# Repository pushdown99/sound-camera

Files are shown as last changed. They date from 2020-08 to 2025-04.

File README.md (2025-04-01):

---
title: (2020) 서울 하드웨어 해커톤 - 탑메이커' 
author: haeyeon.hwang
tags: [tizen, rpi, iot]
---

# (2020)서울하드웨어해커톤 - 탑메이커
---
1. [팀명 및 팀원](#팀명-및-팀원)
2. [프로젝트 제목](#프로젝트-제목) 
3. [프로젝트 배경 및 목적](#프로젝트-배경-및-목적)
4. [타이젠 오픈소스에 컨트리뷰션한 내역](#타이젠-오픈소스에-컨트리뷰션한-내역)
5. [파일리스트](#파일리스트)
6. [코드 기여자](#코드-기여자)
7. [보드](#보드)
8. [구현 사항 가산점](#구현-사항-가산점)

---

[별첨](#별첨)

Watch the video (https://www.youtube.com/watch?v=p-jtZBpTV6w)
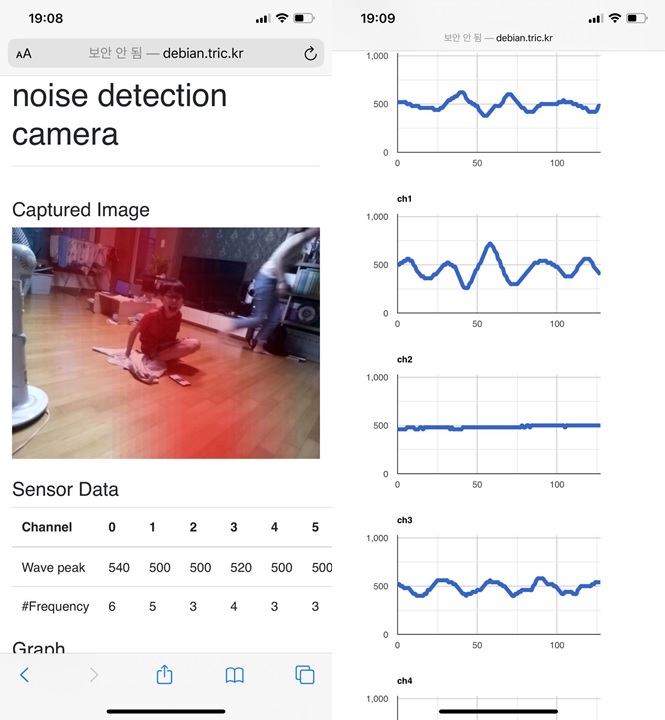
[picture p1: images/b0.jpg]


---

## 팀명 및 팀원
- 팀명: WNB
- 팀원 
   
이름|역할
---|---
황해연|기획/설계/개발(하드웨어/소프트웨어)
김민전|개발(소프트웨어)
황인규|기획/테스트
황인후|테스트

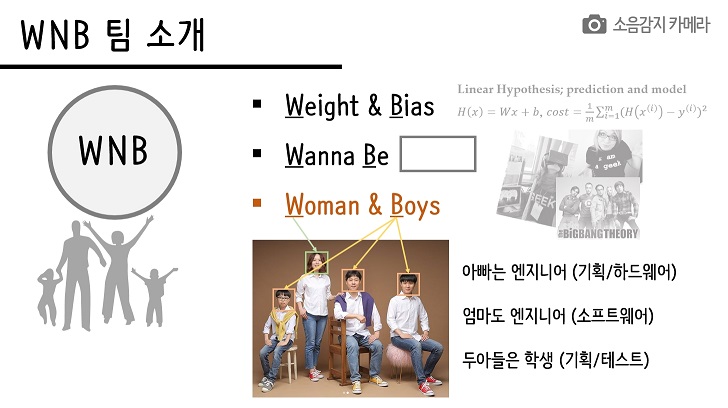
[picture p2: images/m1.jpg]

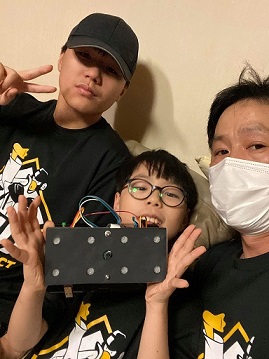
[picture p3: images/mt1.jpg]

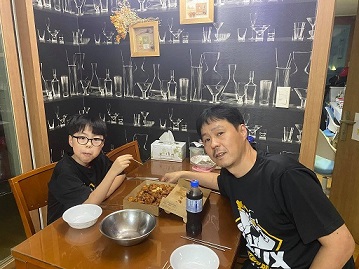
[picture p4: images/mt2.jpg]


---

## 프로젝트 제목

**소음감지 카메라 (Noise detection camera)**

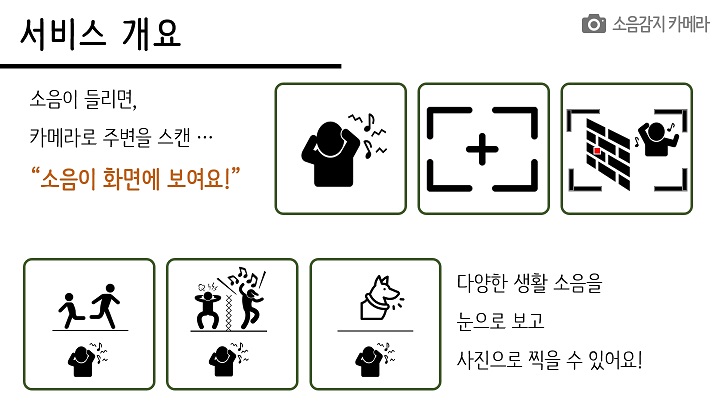
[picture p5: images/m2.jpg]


---

## 프로젝트 배경 및 목적 
#### 배경
- 코로나확산 따른 재택근무, 개학연기, 외출자제 추세
- 집콕족 증가에 따른이웃 간 층간소음 갈등 급증
- 소음원인별 층간소음 분류, 원인미상의 층간소음이 13%
- 층간소음의 사후증명은 어렵고, 분쟁의 불씨가 여전함

#### 하고자 하는것
- 층간소음이나 기타 원인음을 카메라처럼 찍을 수 있다면?
- **소음감지카메라**

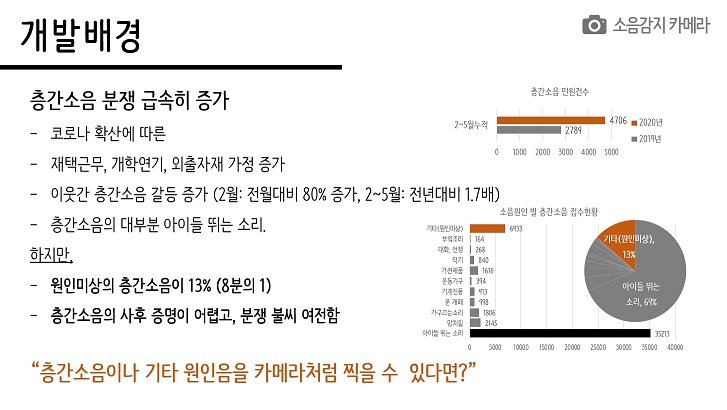
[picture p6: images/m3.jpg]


---

## 타이젠 오픈소스에 컨트리뷰션한 내역
내역없음

---

## 파일리스트
  
#### 소음감지카메라 [[github]](https://github.com/pushdown99/sound-camera/tree/master/camera)
~~~console
├─camera
│  ├─inc
│  ├─shared
│  │  └─res
│  └─src
~~~

- 헤더파일(*.h)

파일명|내용
---|---
inc/baseUI.h|baseUI/EFL 관련 외부참조 및 함수정의 
inc/cam.h|카메라 관련 외부참조 변수 및 함수정의
inc/max4466.h|마이크앰프(MAX4466) 제어를 위한 외부참조 변수 및 함수정의
inc/misc.h|기타(miscellaneous) 외부참조 변수 및 함수정의
inc/piezoe.h|피에조 부저 (카메라셔터음) 제어 관련 외부참조 변수 및 함수정의
inc/post.h|외부서버에 데이터전송을 위한 curl/POST 관련 외부참조 변수 및 함수정의
inc/soundcam.h|소음감지어플리케션 주요구조체 및 관련 외부참조 변수 및 함수정의
inc/thread.h|쓰레드 처리를 위한 외부참조 변수 및 함수정의

- 소스파일(*.c)

파일명|내용
---|---
src/baseUI.c|baseUI/EFL을 이용 UI레이아웃 설정 및 제어 
src/cam.c|카메라 초기화 및 프리뷰관련 설정</br>baseUI와 연결
src/**main.c**|어플리케이초기화 및 환경설정</br>idler설정
src/max4466.c|마이크앰프(MAX4466) 제어를 위한 외부참조 변수 및 함수정의
src/misc.c|기타(miscellaneous) 함수
src/piezoe.c|피에조 부저 (카메라셔터음) 제어
src/post.c|외부서버에 데이터전송을 위한 curl/POST 
src/thread.c|쓰레드 처리 (마이크앰프별,코디네이터, GPIO, Thingspark 연동)

#### 카메라 대시보드 [[github]](https://github.com/pushdown99/sound-camera/tree/master/dashboard)

~~~console
├─dashboard
│  ├─public
│  │  └─data
│  └─views
~~~

- 소스파일(*.js)

파일명|내용
---|---
**app.js**|nodejs기반 웹어플리케이션  

- 소스파일(*.ejs)
  
파일명|내용
---|---
views/chart.ejs|google chart 및 카메라 이미지처리 html/javascript 템플릿  

---

## 코드 기여자 

#### 소음감지카메라

- 헤더파일(*.h)

파일명|기여자
---|---
inc/baseUI.h|황해연 
inc/cam.h|황해연
inc/max4466.h|황해연
inc/misc.h|황해연,김민전
inc/piezoe.h|황해연,김민전
inc/post.h|황해연
inc/soundcam.h|황해연
inc/thread.h|황해연

- 소스파일(*.c)

파일명|기여자
---|---
src/baseUI.c|황해연
src/cam.c|황해연
src/main.c|황해연
src/max4466.c|황해연
src/misc.c|황해연
src/piezoe.c|황해연
src/post.c|황해연 
src/thread.c|황해연

#### 카메라 대시보드

- 소스파일(*.js)

파일명|기여자
---|---
app.c|황해연

- 소스파일(*.ejs)
  
파일명|기여자
---|---
views/chart.ejs|황해연  

---

## 보드 

구현보드|목적|소스위치
:---|:---|:---
RPi 4|소음감지 카메라 본체</br>- 마이크앰프처리</br>- 카메라영상출력|[https://github.com/pushdown99/sound-camera/tree/master/camera](https://github.com/pushdown99/sound-camera/tree/master/camera)  

---

## 구현 사항 (가산점) 

#### Peripheral
종류|디바이스|목적|소스위치
:---|:---|:---|:---
SPI|MAX4466/MCP3008|마이크앰프 복수채널 I/O|src/mcp3008.c</br>src/max446.c
GPIO|버튼|카메라셔터|src/thread.c
GPIO|피에조부저|카메라셔터음|src/piezoe.c 

---

## 별첨

#### 자료다운로드
Output|Download
---|---
문서자료|[소음카메라(pptx)](noise-camera.pptx)
문서자료|[소음카메라(pdf)](noise-camera.pdf)
발표자료|[PRESENTATION.md](PRESENTATION.md)

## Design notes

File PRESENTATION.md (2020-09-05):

---
title: (2020) 서울 하드웨어 해커톤 - 탑메이커' 
author: haeyeon.hwang
tags: [tizen, rpi, iot]
---

# (2020)서울하드웨어해커톤 - 탑메이커

---
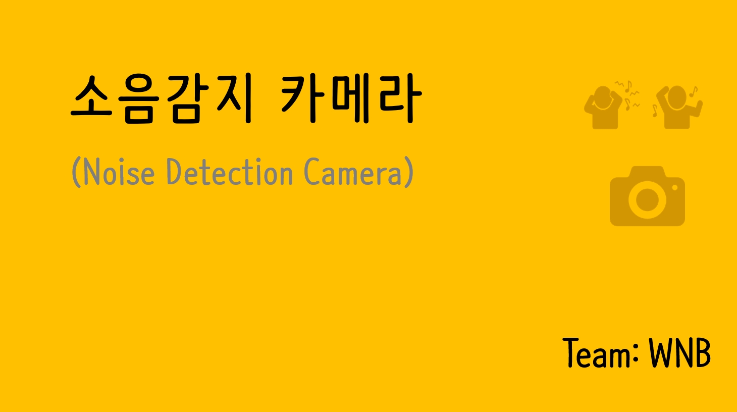
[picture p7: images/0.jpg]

---
1. [WNB 팀소개](#page-1)
2. [서비스 개요](#page-2) 
3. [개발 배경](#page-3)
4. [제작하기](#page-4)
5. [시스템 구성](#page-10)
6. [결과물](#page-11)
7. [시연](#시연)

Watch the video (https://www.youtube.com/watch?v=p-jtZBpTV6w)

---

###### Page 1
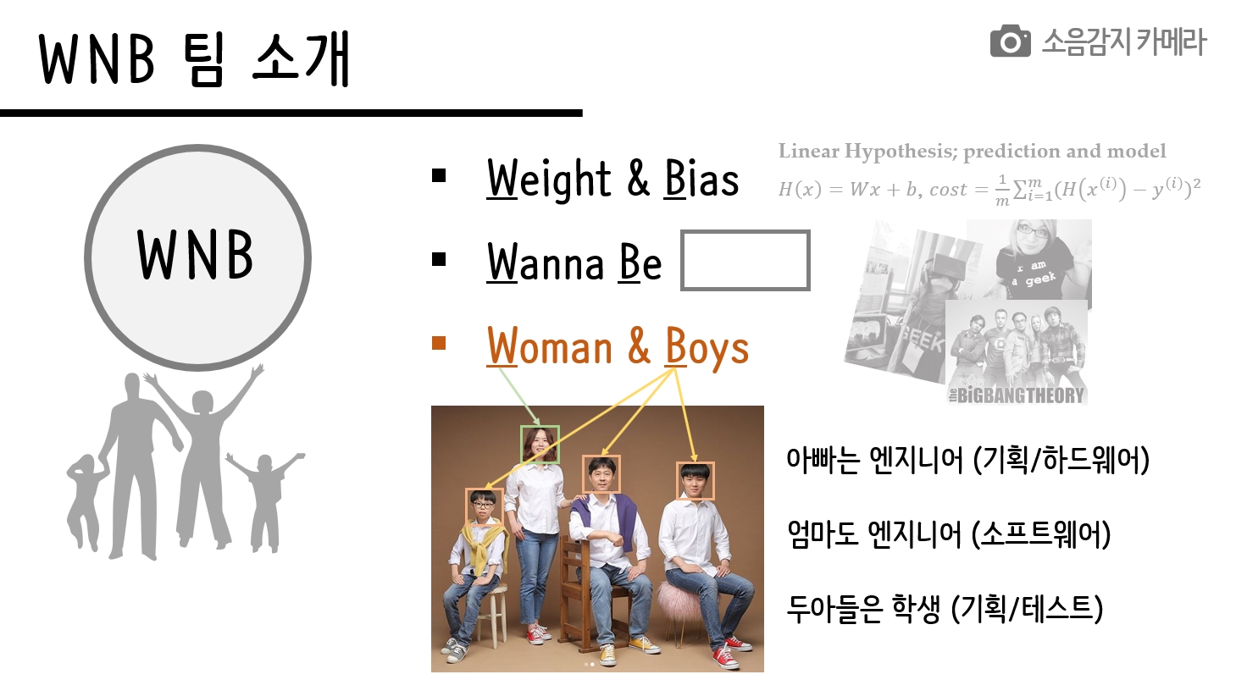
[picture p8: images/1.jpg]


---

###### Page 2
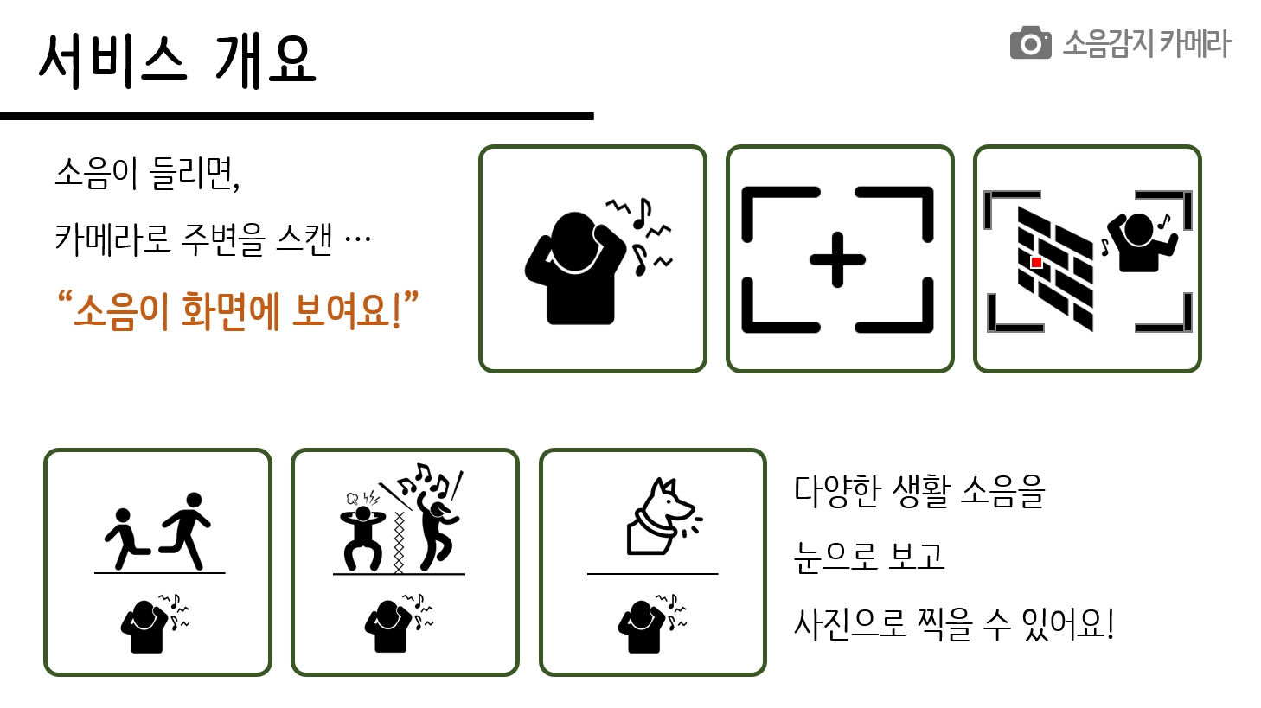
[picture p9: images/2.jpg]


---

###### Page 3
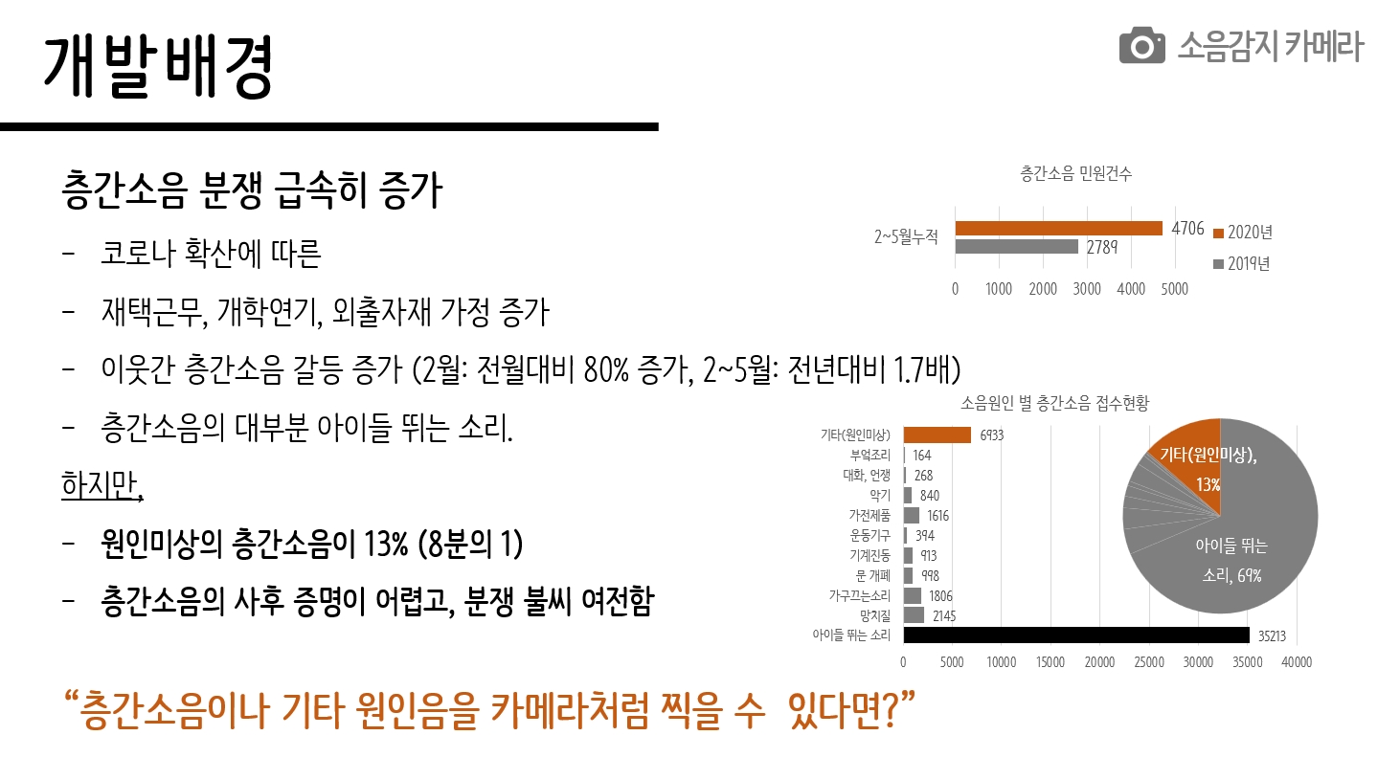
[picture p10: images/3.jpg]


---

###### Page 4
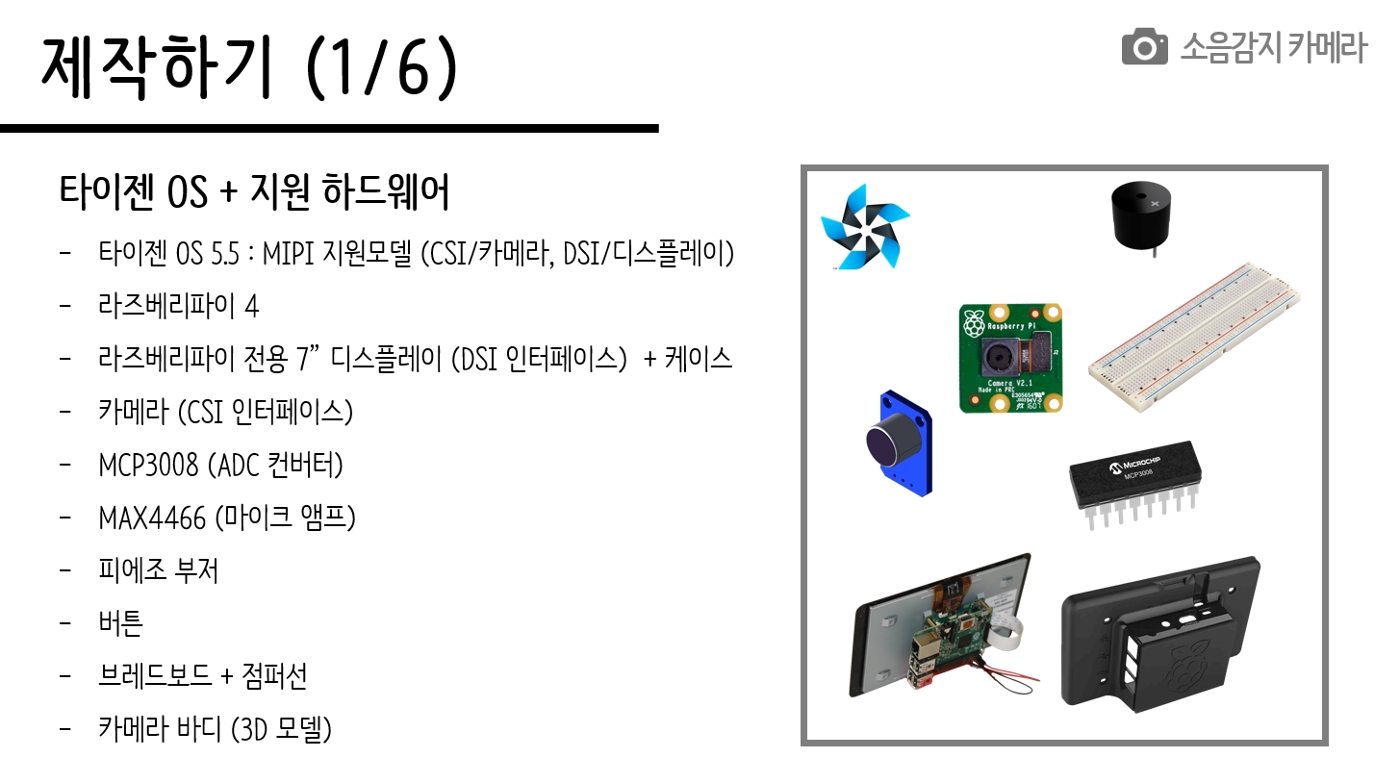
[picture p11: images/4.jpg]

###### Page 5
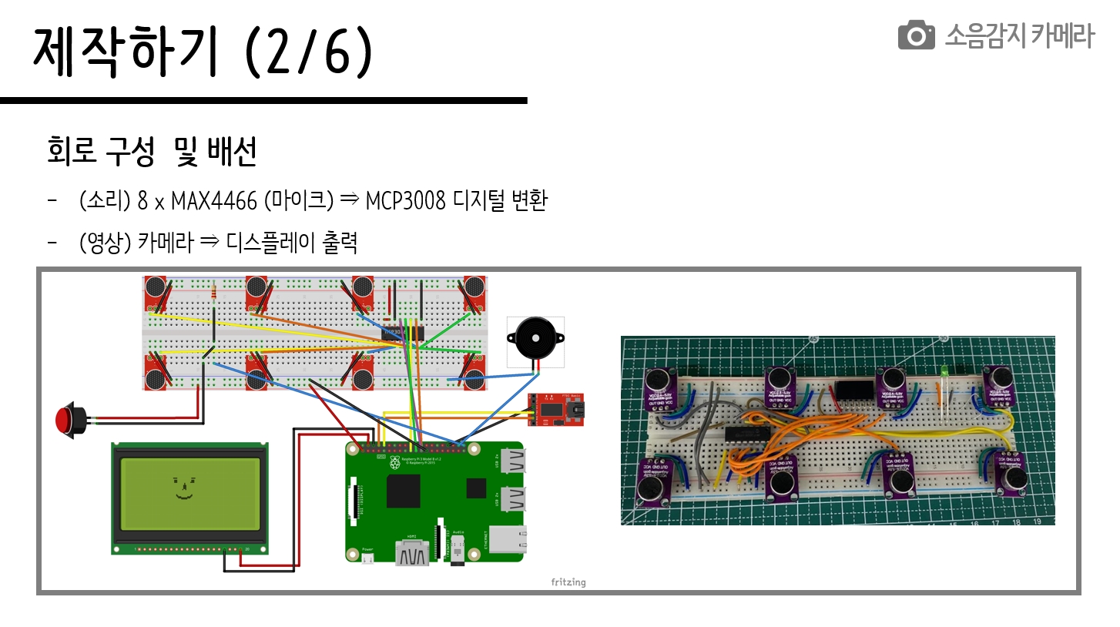
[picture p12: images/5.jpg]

###### Page 6
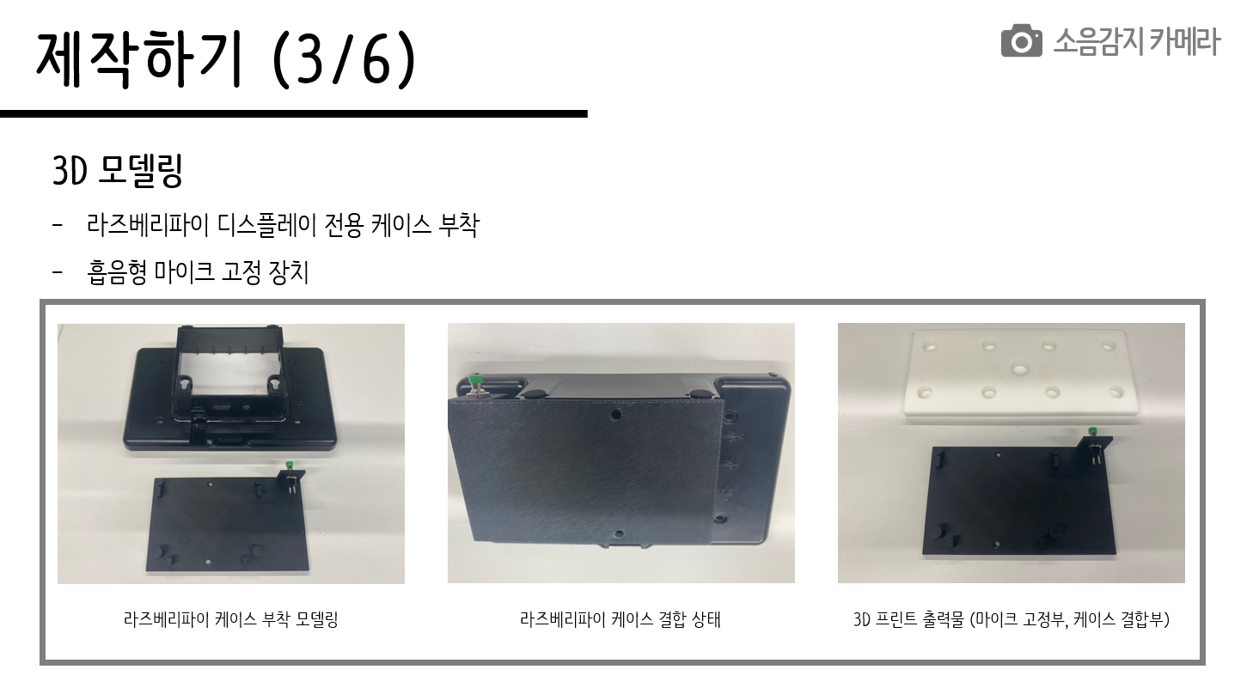
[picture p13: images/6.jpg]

###### Page 7
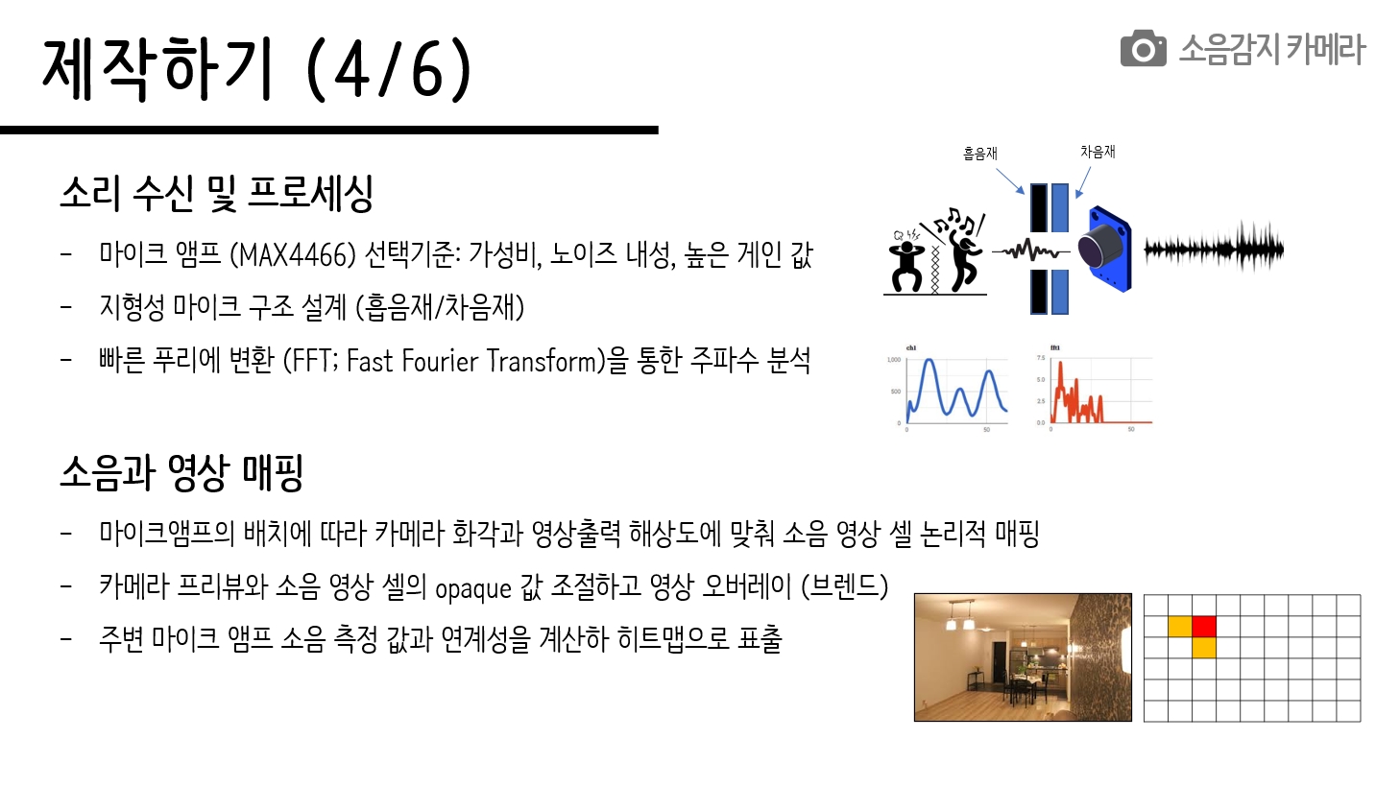
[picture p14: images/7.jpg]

###### Page 8
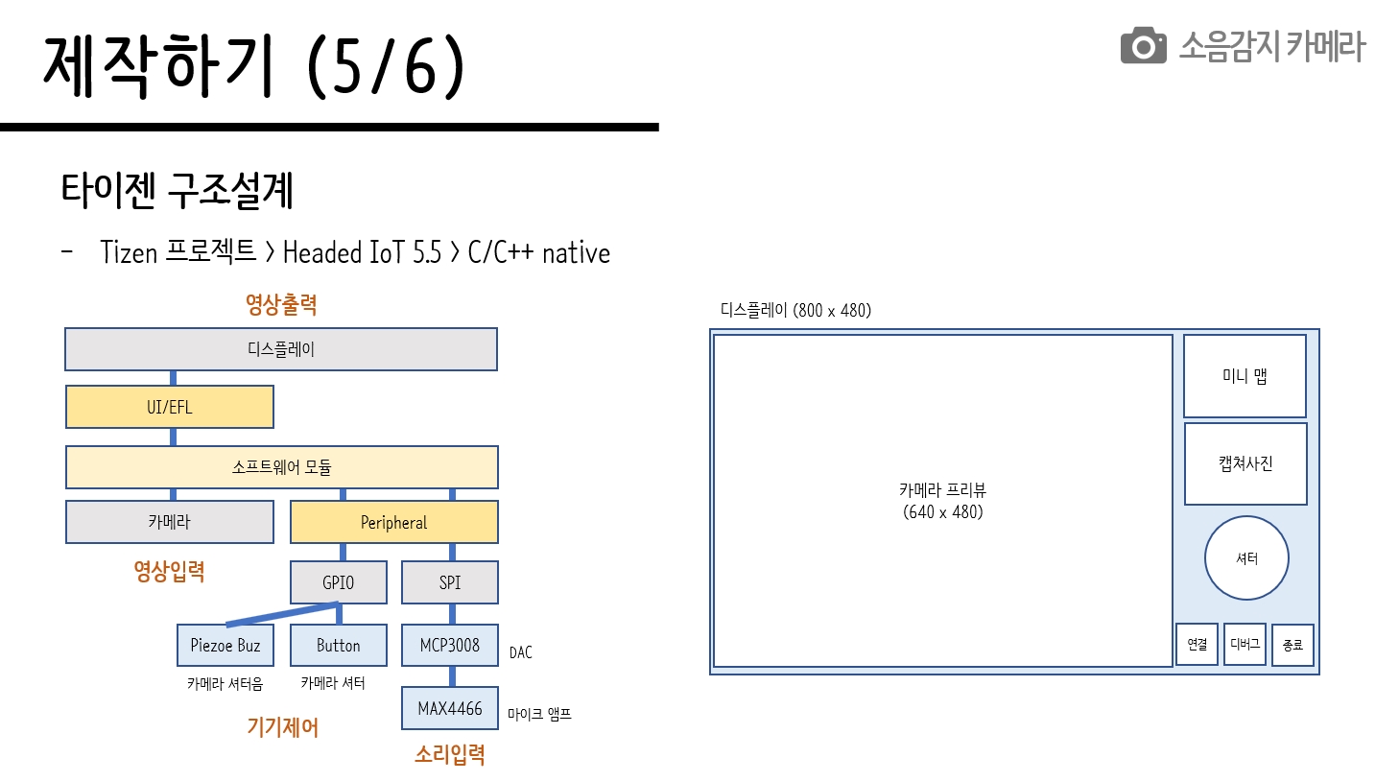
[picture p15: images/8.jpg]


* 디스플레이 UI 구성을 위한 레이아웃 설계

~~~ㅊ
/*
 *  DISPLAY SCREEN LAYOUT
 *  =====================
 *
 *  - Raspberry Pi 7" Touch Screen Display (800 x 600)
 *
 *   <------------ 640 --------------> <----- 160 ----->
 * 	+---------------------------------+-----------------+
 * 	|(0,0)                            | +-------------+ |    noise map
 * 	|                                 | |  NOISE MAP  | |    (120 x 90; 4:3)
 * 	|         CAMERA PREVIEW          | |             | |
 * 	|          (640 x 480)            | +-------------+ |
 * 	|                                 | +-------------+ |
 * 	|                                 | |  SHUTTER    | |
 * 	|                                 | +-------------+ |
 * 	|                                 | +-------------+ |
 * 	|                                 | |  EXIT       | |
 * 	|                        (640,480)| +-------------+ |
 * 	+---------------------------------+-----------------+
 * 	                                   <>              <> 20 (BORDER)
 *                                       <----120----->
 *
 *  SENSOR LAYOUT @CAMERA PREVIEW
 *  =============================
 *
 *  - SCREEN: width x height  = 640 x 380 (4:3)
 *  - SENSOR: width x height  = 160 x 240
 *
 *  <--------------------------640-------------------------->
 *  <----160------> width
 * 	+-------------+-------------+-------------+-------------+
 * 	|             |             |             |             |
 * 	|             |             |             |             |
 * 	|             |             |             |             |
 * 	|  SENSOR#0   |  SENSOR#1   |  SENSOR#2   |  SENSOR#3   |
 * 	|             |             |             |             |
 * 	|             |             |             |             |
 * 	|             |             |             |             |
 * 	|             |             |             |             |
 * 	+-------------+-------------+-------------+-------------+
 * 	|             |             |             |             |
 * 	|             |             |             |             |
 * 	|             |             |             |             |
 * 	|  SENSOR#4   |  SENSOR#5   |  SENSOR#6   |  SENSOR#7   |
 * 	|             |             |             |             |
 * 	|             |             |             |             |
 * 	|             |             |             |             |
 * 	|             |             |             |             |
 * 	+-------------+-------------+-------------+-------------+
 *
 *  HEATMAP CELL LAYOUT @SENSOR
 *  ===========================
 *
 *	- SENSOR: width x height = 160 x 240
 *	- CELL: width x height = 16 x 24 (10 x 10 matrix)
 *  <-16->
 *  +----+----+----+----+----+----+----+----+----+----+
 *  | 00 | 01 | 02 | 03 | 04 | 05 | 06 | 07 | 08 | 08 |
 *  +----+----+----+----+----+----+----+----+----+----+
 *  | 01 |    |    |    |    |    |    |    |    |    |
 *  +----+----+----+----+----+----+----+----+----+----+
 *  | 02 |    |    |    |    |    |    |    |    |    |
 *  +----+----+----+----+----+----+----+----+----+----+
 *  | 03 |    |    |    |    |    |    |    |    |    |
 *  +----+----+----+----+----+----+----+----+----+----+
 *  | 04 |    |    |    |    |    |    |    |    |    |
 *  +----+----+----+----+----+----+----+----+----+----+
 *  | 05 |    |    |    |    |    |    |    |    |    |
 *  +----+----+----+----+----+----+----+----+----+----+
 *  | 06 |    |    |    |    |    |    |    |    |    |
 *  +----+----+----+----+----+----+----+----+----+----+
 *  | 07 |    |    |    |    |    |    |    |    |    |
 *  +----+----+----+----+----+----+----+----+----+----+
 *  | 08 |    |    |    |    |    |    |    |    |    |
 *  +----+----+----+----+----+----+----+----+----+----+
 *  | 09 |    |    |    |    |    |    |    |    |    |
 *  +----+----+----+----+----+----+----+----+----+----+
 *
 */
~~~

* 어플리케이션 데이터 자료구조 (structure)
~~~c
typedef struct {
	int			id;								// sensor #id
	int     	p;								// peak value
	int     	n;                  			// frequency count
	int			o;								// opaque (0..255)
	int			v[NSAMPLE];						// sensor read value
	int 		f[NSAMPLE];						// fast fourier transform matrix mapping value
	double 		a[NSAMPLE];						// fast fourier transform matrix
	void* 		data;
} max4466_t;

typedef struct appdata {
	int 		verbose;						// verbose
	int 		network;						// network availability
	int 		nfail;							// #fail (peer server no response?)
	int			peak;							// noise peak
	int 		freq;							// noise frequency
	int         snap;                        	// please snapshot
	bool		snapshot;
	max4466_t	max4466[NSENSOR];
	int 		s[R_SENSOR][C_SENSOR];			// sensor map opaque
	int         h[R_HEATMAP][C_HEATMAP];		// heat map opaque

	Evas_Object *win;							// baseUI frame object
	Evas_Object *evas;							// windows child object
	Evas_Object *view;							// camera preview object
	Evas_Object *ctrl;							// camera control object
	Evas_Object *heatmap[R_HEATMAP][C_HEATMAP]; // heat map rectangle object
	Evas_Object *minimap[R_SENSOR][C_SENSOR]; 	// heat map rectangle object
	Evas_Object *overlay[R_SENSOR][C_SENSOR]; 	// heat map rectangle object
	Evas_Object *thumbnail;						// thumbnail
	Evas_Object *shot;							// button
	Evas_Object *shot2;							// button
	Evas_Object *conn;							// connection button
	Evas_Object *disc;							// disconnection button
	Evas_Object *debug;							// debug button
	Evas_Object *debug2;						// debug button
	Evas_Object *exit;							// exit

	Ecore_Idler *idler;
	Ecore_Timer *timer;
} appdata_t;
~~~

###### Page 9
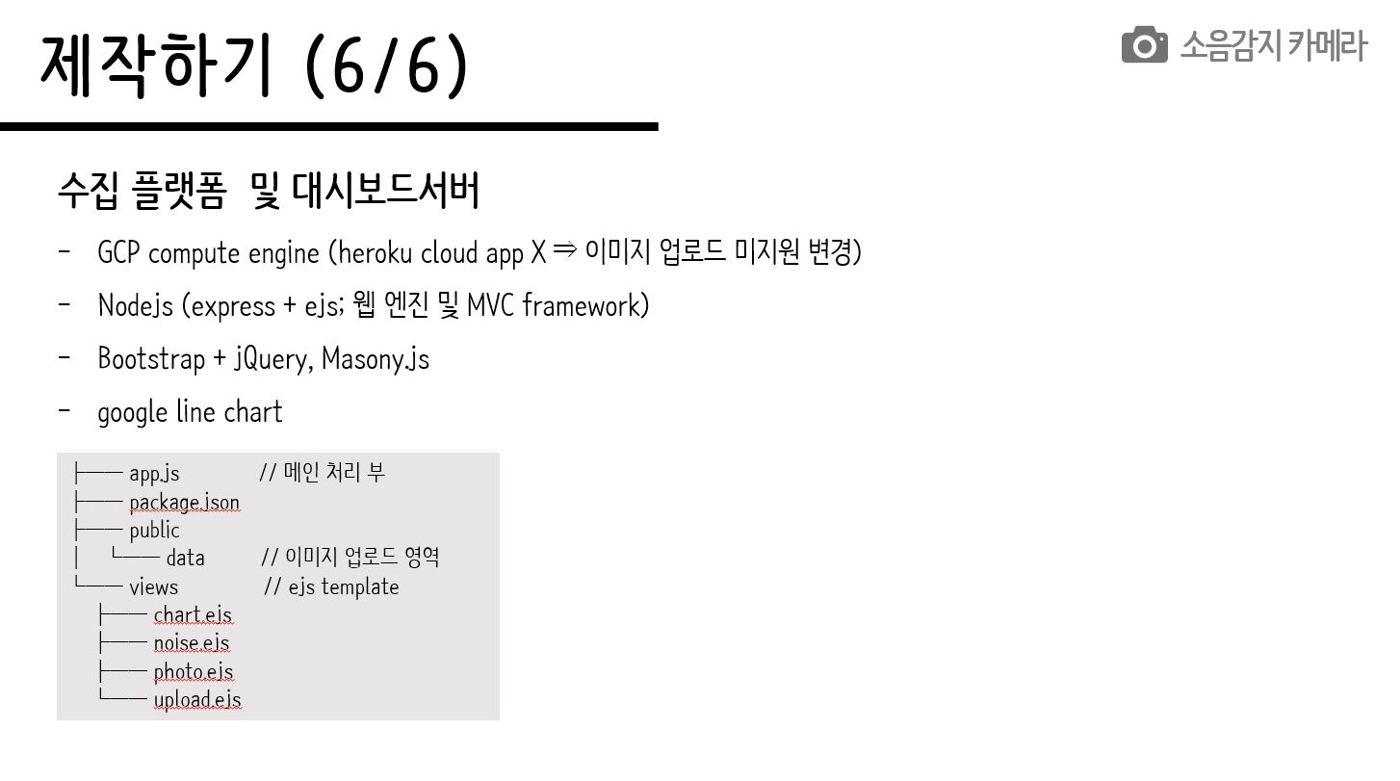
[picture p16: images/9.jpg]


---

###### Page 10
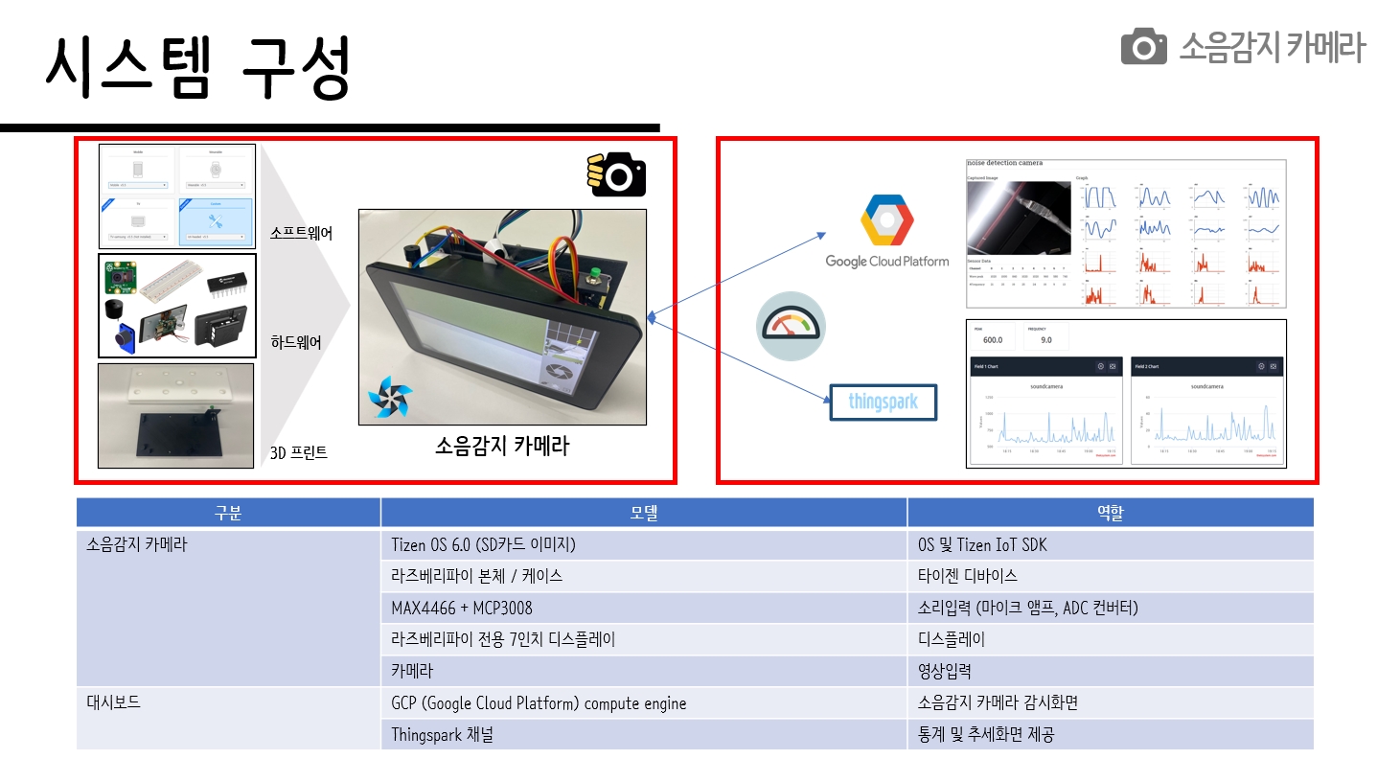
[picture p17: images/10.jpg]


---

###### Page 11
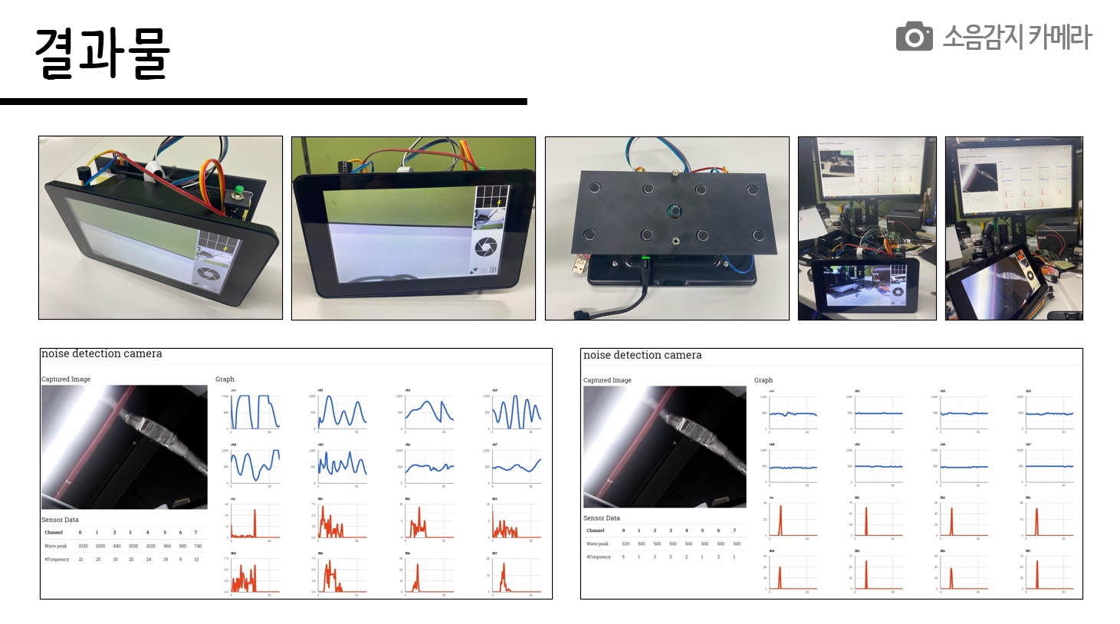
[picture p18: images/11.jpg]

###### Page 12
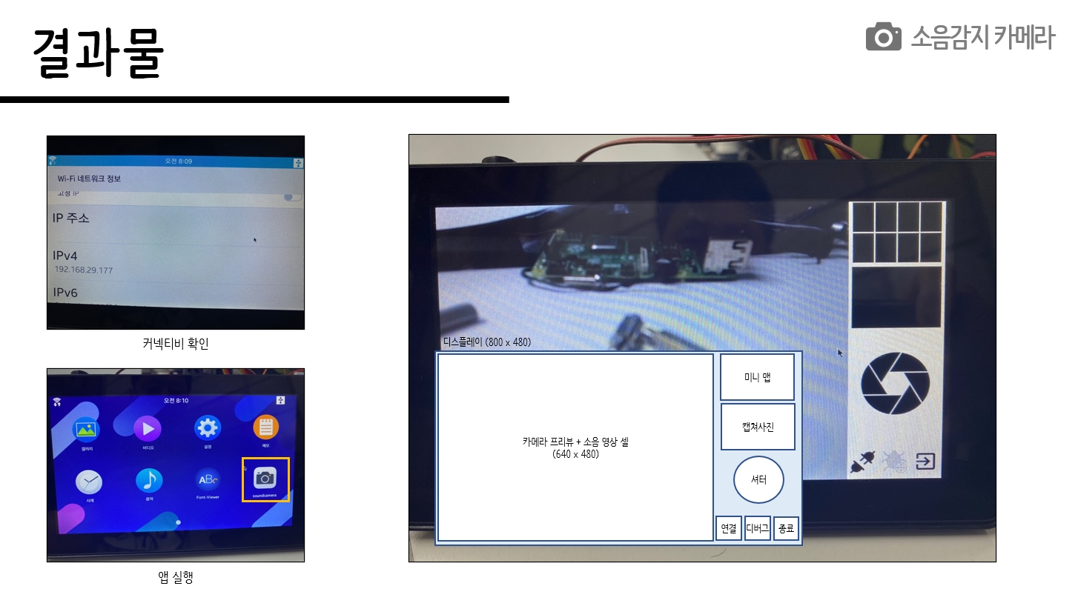
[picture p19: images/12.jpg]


---

## 시연

#### 시연절차
1) 소음감지 카메라전원 ON (외부전원 또는 휴대용배터리>2.3A USB케이블)
2) 와이파이(WiFi) 연결상태 확인 (SSID 및 할당된 IPv4 주소확인)
3) 동일 네트워크에 연결된 노트북에서 원격디바이스 접속 (디버깅용)
   ~~~console
   C:\> sdb connect {ip주소}
   C:\> sdb root on
   C:\> sdb shell
   sh # dlogutil soundcamera
   ~~~

4) 노트북에서 소음감지 카메라 [모니터링 웹 접속](http://debian.tric.kr:9900)
4) 노트북에서 소음감지 카메라 [클라우드 웹 접속](https://thingspark.co.kr/channels/65697)
5) 소음감지카메라 어플리케이션기동
6) 어플리케이션에서 서버와 접속여부 아이콘 확인
7) 어플리케이션에서 디버깅 아이콘 ON/OFF
8) 어플리케이션에서 사진찍어 업로드하기 (물리버튼 또는 화면버튼 클릭)
9) 모니터링화면에 사진이 업로드되는지 확인
10) 소리나는 주변을 스캔하고 사진찍기

Watch the video (https://www.youtube.com/watch?v=p-jtZBpTV6w)

#### 대시보드 (dashboard)

대시보드연동|화면|링크
---|---|---
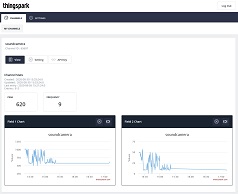
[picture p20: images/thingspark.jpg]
||[https://thingspark.co.kr/channels/65697](https://thingspark.co.kr/channels/65697)
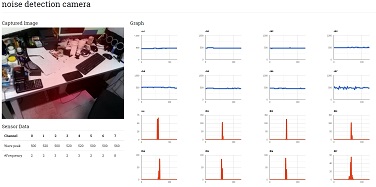
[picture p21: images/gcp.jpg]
||[http://debian.tric.kr:9900/](http://debian.tric.kr:9900/)

---

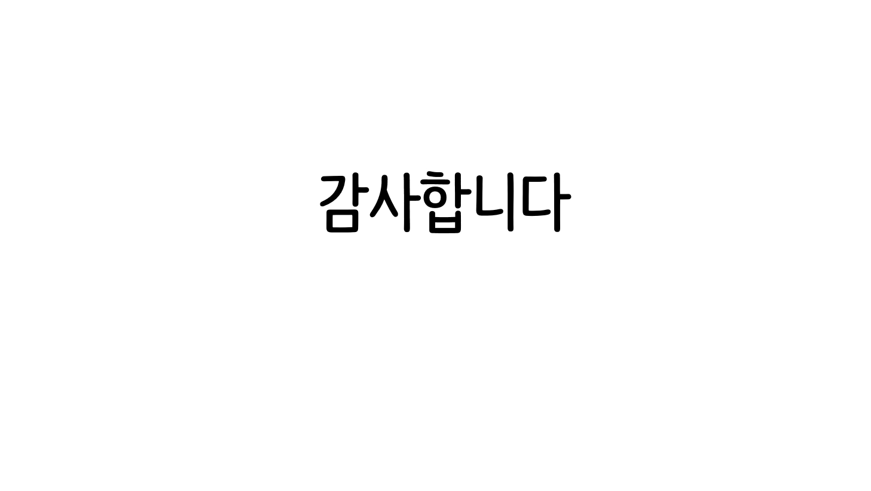
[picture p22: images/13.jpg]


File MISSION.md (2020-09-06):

---
title: (2020) 서울 하드웨어 해커톤 - 탑메이커' 
author: haeyeon.hwang
tags: [tizen, rpi, iot]
---

# (2020)서울하드웨어해커톤 - 탑메이커
---
1. [미션1 (8/01)](#미션1)
2. [미션2 (8/08)](#미션2) 
3. [미션3 (8/16)](#미션3)
4. [미션4 (8/29)](#미션4)

---

##  미션1
- Tizen XAML App 프로젝트 생성하기
- 참고사이트: [https://tizenschool.org/tutorial/194/contents/14](https://tizenschool.org/tutorial/194/contents/14)
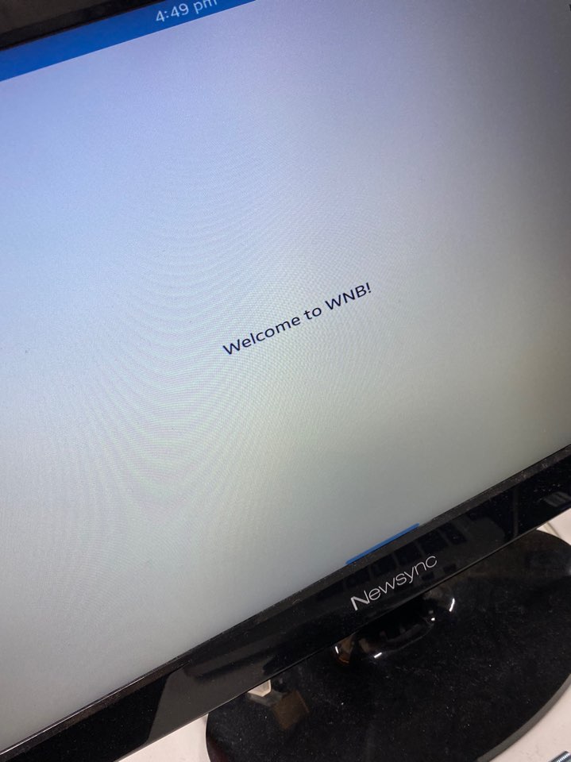
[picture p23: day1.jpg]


---

##  미션2
- MyIP: 자신 IP주소를 출력하는 어플리케이션 만들기
- Tizen XAML App
- 참고사이트: [https://tizenschool.org/tutorial/197/contents/2](https://tizenschool.org/tutorial/197/contents/2)
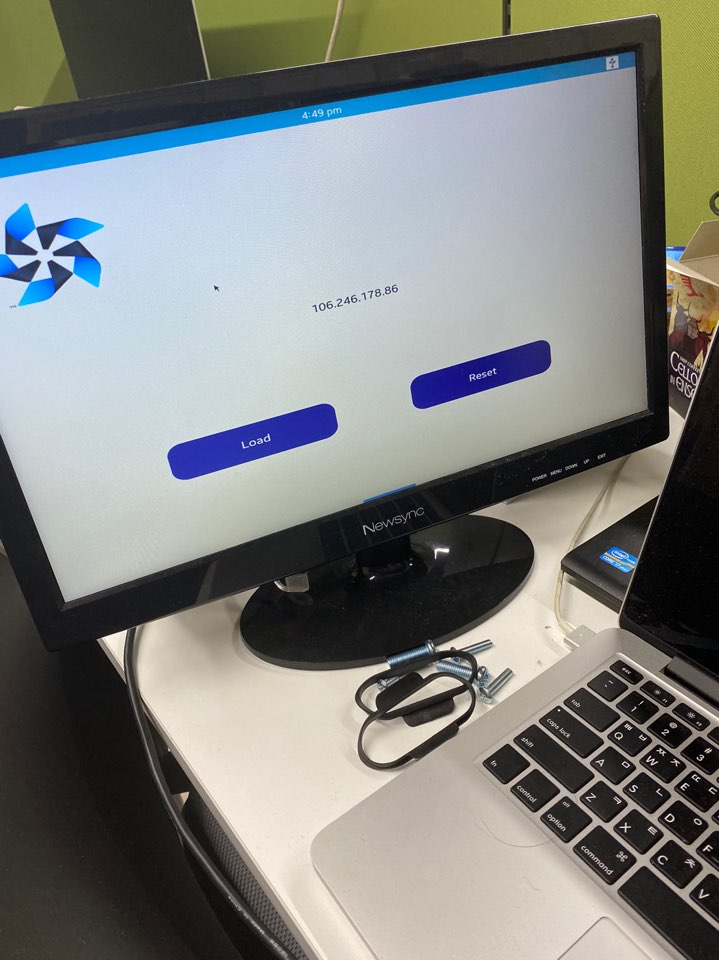
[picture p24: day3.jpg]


---

## 미션3
- 헤드리스기 어플리케이션을 실행하는 방법 
~~~console
C:\> sdb connect {ip address}
C:\> sdb root on
C:\> sdb shell
sh# service {application}
~~~

---
##  미션4

- C#어플리케이션에서 C API를 호출하는 방법
  
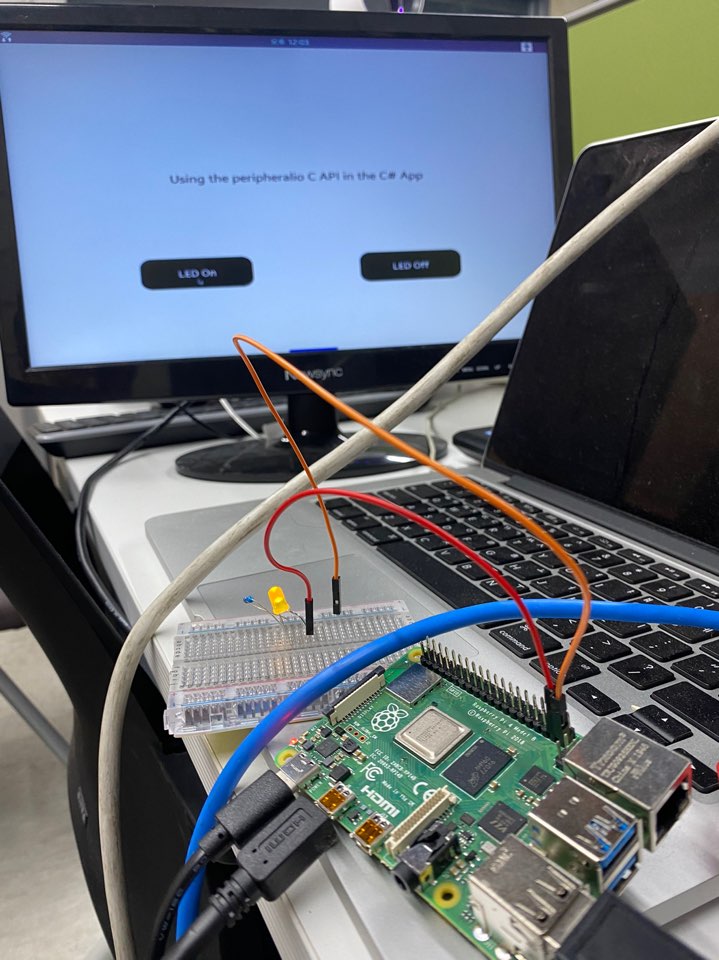
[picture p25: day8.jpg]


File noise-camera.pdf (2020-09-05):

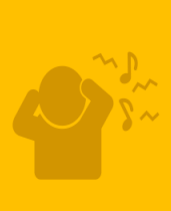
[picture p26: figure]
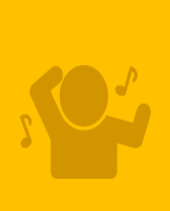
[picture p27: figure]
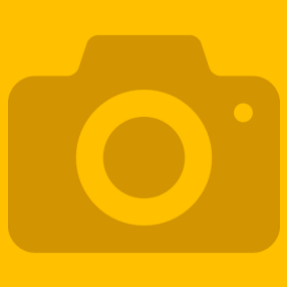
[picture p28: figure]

# Team: WNB

# 소음감지 카메라

# (Noise Detection Camera)

# - Weight & Bias

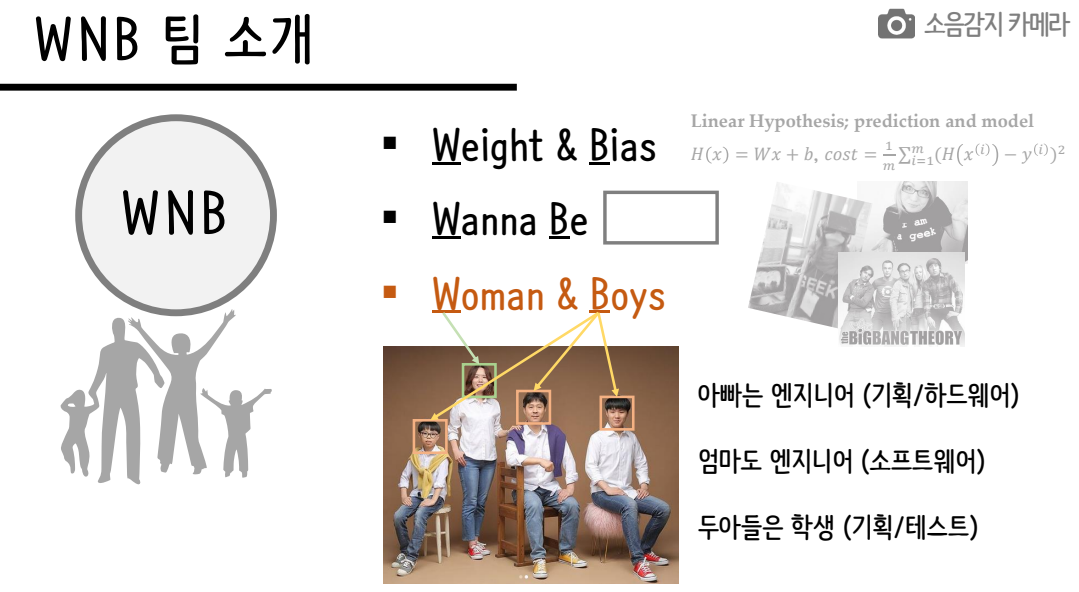
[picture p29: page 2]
WNB 팀 소개; 소음감지 카메라; ▪ Wanna Be; ▪ Woman & Boys; WNB

Linear Hypothesis; prediction and model
H x = Wx + b, cost =

아빠는 엔지니어 (기획/하드웨어)

엄마도 엔지니어 (소프트웨어)

두아들은 학생 (기획/테스트)

서비스 개요 | 소음감지 카메라

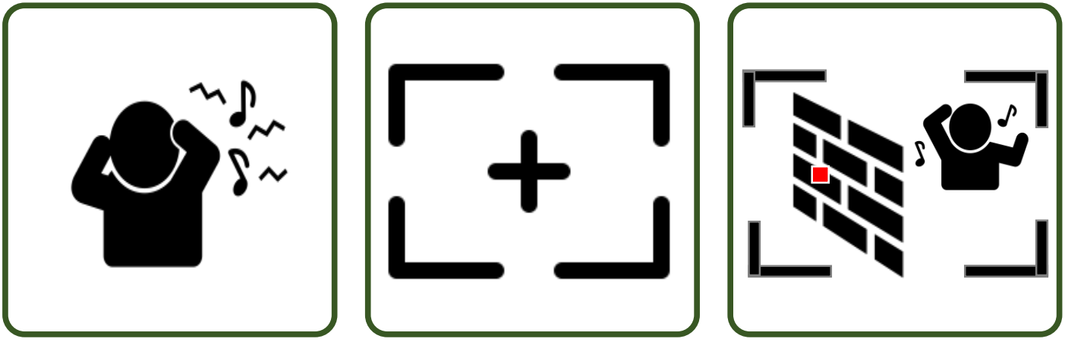
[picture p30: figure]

소음이 들리면,

## 카메라로 주변을 스캔 …

## “소음이 화면에 보여요!”


## 다양한 생활 소음을

## 눈으로 보고

## 사진으로 찍을 수 있어요!

## 층간소음 분쟁 급속히 증가

- 코로나 확산에 따른
- 재택근무, 개학연기, 외출자재 가정 증가
- 이웃간 층간소음 갈등 증가 (2월: 전월대비 80% 증가, 2~5월: 전년대비 1.7배)
- 층간소음의 대부분 아이들 뛰는 소리.

하지만,

- 원인미상의 층간소음이 13% (8분의 1)
- 층간소음의 사후 증명이 어렵고, 분쟁 불씨 여전함
개발배경 | 소음감지 카메라

2789

4706

0 1000 2000 3000 4000 5000

2~5월누적

층간소음 민원건수

2020년

2019년

아이들 뛰는 소리; 망치질; 가구끄는소리; 기계진동; 운동기구; 가전제품; 부엌조리; 기타(원인미상); 소음원인 별 층간소음 접수현황; 아이들 뛰는; 기타(원인미상),

## “층간소음이나 기타 원인음을 카메라처럼 찍을 수 있다면?”


## 타이젠 OS + 지원 하드웨어

- 타이젠 OS 5.5 : MIPI 지원모델 (CSI/카메라, DSI/디스플레이)
- 라즈베리파이 4
- 라즈베리파이 전용 7” 디스플레이 (DSI 인터페이스) + 케이스
- 카메라 (CSI 인터페이스)
- MCP3008 (ADC 컨버터)
- MAX4466 (마이크 앰프)
- 피에조 부저
- 버튼
- 브레드보드 + 점퍼선
- 카메라 바디 (3D 모델)
제작하기 (1/6) | 소음감지 카메라

## 회로 구성 및 배선

제작하기 (2/6) | 소음감지 카메라


- (소리) 8 x MAX4466 (마이크) ⇒ MCP3008 디지털 변환
- (영상) 카메라 ⇒ 디스플레이 출력

## 3D 모델링

제작하기 (3/6) | 소음감지 카메라


- 라즈베리파이 디스플레이 전용 케이스 부착
- 흡음형 마이크 고정 장치
라즈베리파이 케이스 부착 모델링 | 라즈베리파이 케이스 결합 상태 | 3D 프린트 출력물 (마이크 고정부, 케이스 결합부)


## 소리 수신 및 프로세싱

- 마이크 앰프 (MAX4466) 선택기준: 가성비, 노이즈 내성, 높은 게인 값
- 지형성 마이크 구조 설계 (흡음재/차음재)
- 빠른 푸리에 변환 (FFT; Fast Fourier Transform)을 통한 주파수 분석
제작하기 (4/6) | 소음감지 카메라
흡음재 | 차음재

## 소음과 영상 매핑


- 마이크앰프의 배치에 따라 카메라 화각과 영상출력 해상도에 맞춰 소음 영상 셀 논리적 매핑


- 카메라 프리뷰와 소음 영상 셀의 opaque 값 조절하고 영상 오버레이 (브렌드)
- 주변 마이크 앰프 소음 측정 값과 연계성을 계산하 히트맵으로 표출

## 타이젠 구조설계

- Tizen 프로젝트 > Headed IoT 5.5 > C/C++ native
제작하기 (5/6) | 소음감지 카메라

카메라 프리뷰 (640 x 480); 캡쳐사진; 디버그

카메라

디스플레이

UI/EFL

소프트웨어 모듈

Peripheral

GPIO | SPI

MCP3008

MAX4466

Piezoe Buz | Button

마이크 앰프

DAC

카메라 셔터음 카메라 셔터

영상입력

소리입력

기기제어

영상출력
디스플레이 (800 x 480)

## 수집 플랫폼 및 대시보드서버

- GCP compute engine (heroku cloud app X ⇒ 이미지 업로드 미지원 변경)
- Nodejs (express + ejs; 웹 엔진 및 MVC framework)
- Bootstrap + jQuery, Masony.js
- google line chart
제작하기 (6/6) | 소음감지 카메라
├── app.js | // 메인 처리 부
├── package.json
├── public
│ └── data | // 이미지 업로드 영역
└── views | // ejs template
├── chart.ejs
├── noise.ejs
├── photo.ejs
└── upload.ejs

소음감지 카메라; Tizen OS 6.0 (SD카드 이미지); OS 및 Tizen IoT SDK; 3D 프린트; 하드웨어; 소프트웨어

| 라즈베리파이 본체 / 케이스 | 타이젠 디바이스
| MAX4466 + MCP3008 | 소리입력 (마이크 앰프, ADC 컨버터)
| 라즈베리파이 전용 7인치 디스플레이 | 디스플레이
| 카메라 | 영상입력
대시보드 | GCP (Google Cloud Platform) compute engine | 소음감지 카메라 감시화면
| Thingspark 채널 | 통계 및 추세화면 제공
시스템 구성 | 소음감지 카메라


결과물 | 소음감지 카메라


결과물 | 소음감지 카메라

커넥티비 확인

앱 실행

카메라 프리뷰 + 소음 영상 셀
(640 x 480)

디스플레이 (800 x 480)

미니 맵

캡쳐사진

셔터

연결 | 디버그 | 종료

# 감사합니다

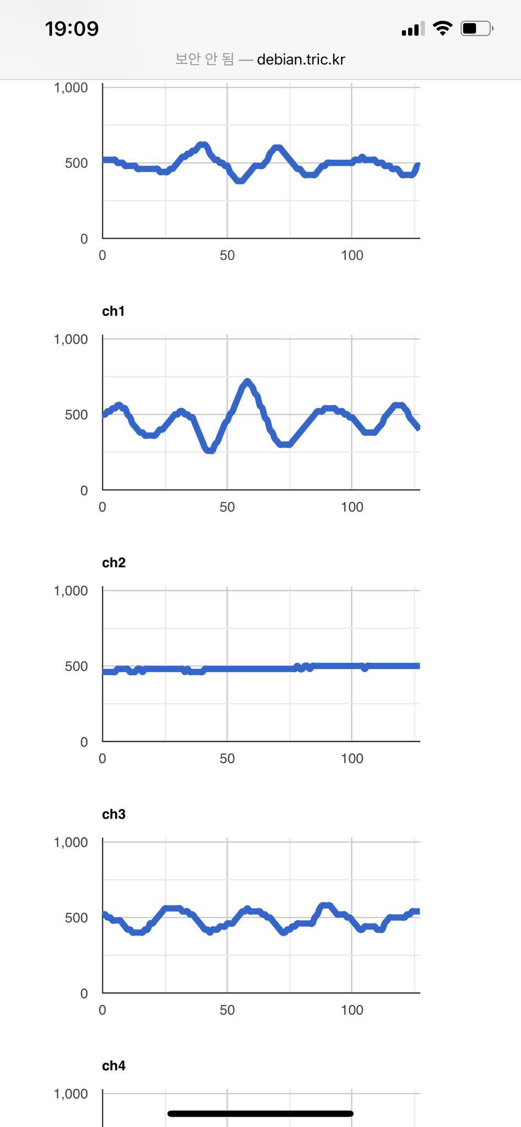
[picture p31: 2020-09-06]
images/b2.jpg

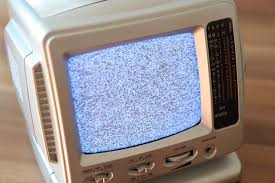
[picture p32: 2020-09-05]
images/a2.jpg

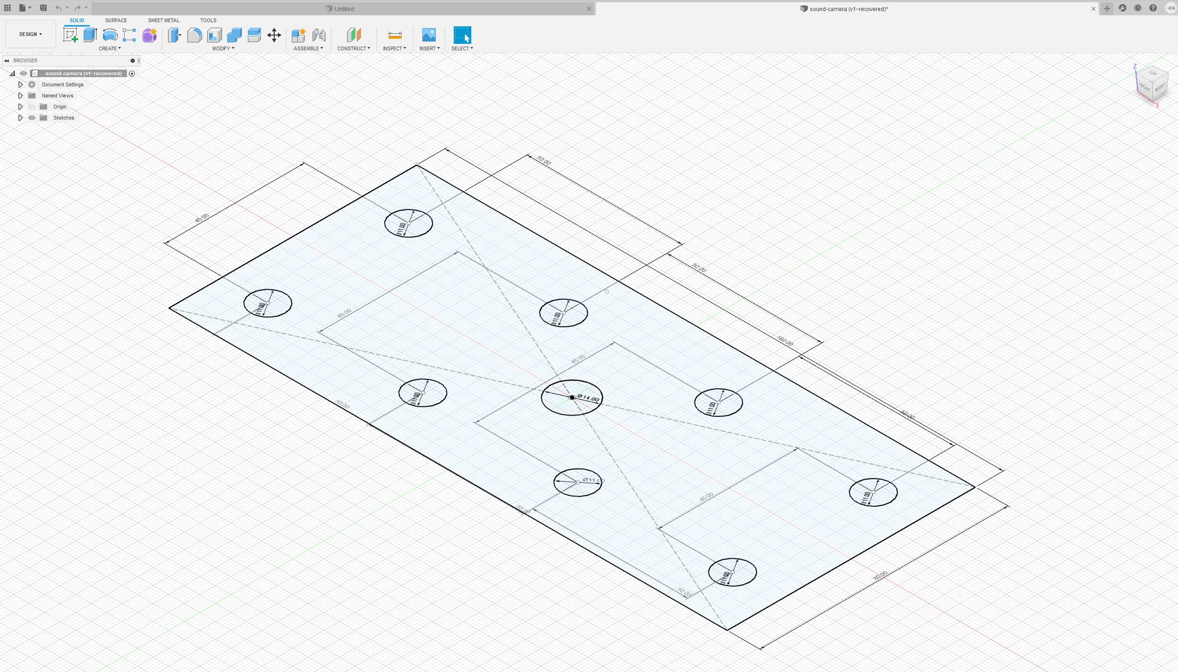
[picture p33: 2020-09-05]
images/fusion.jpg

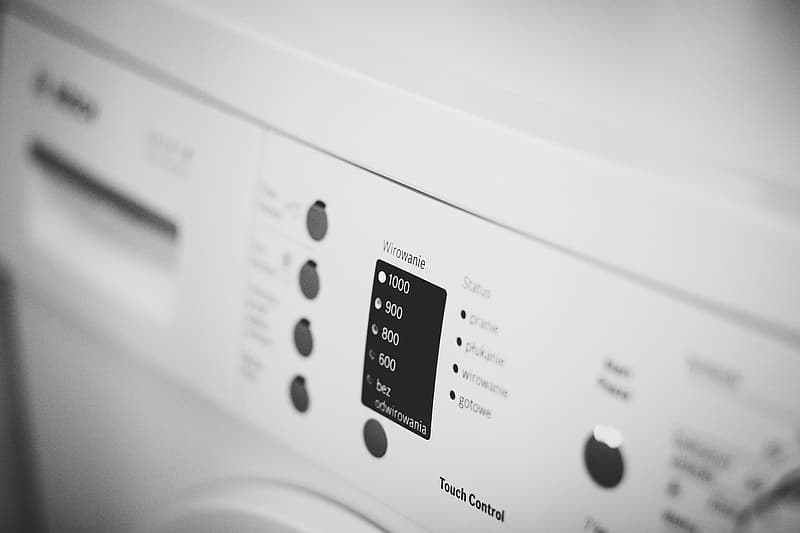
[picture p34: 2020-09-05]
images/a5.jpg

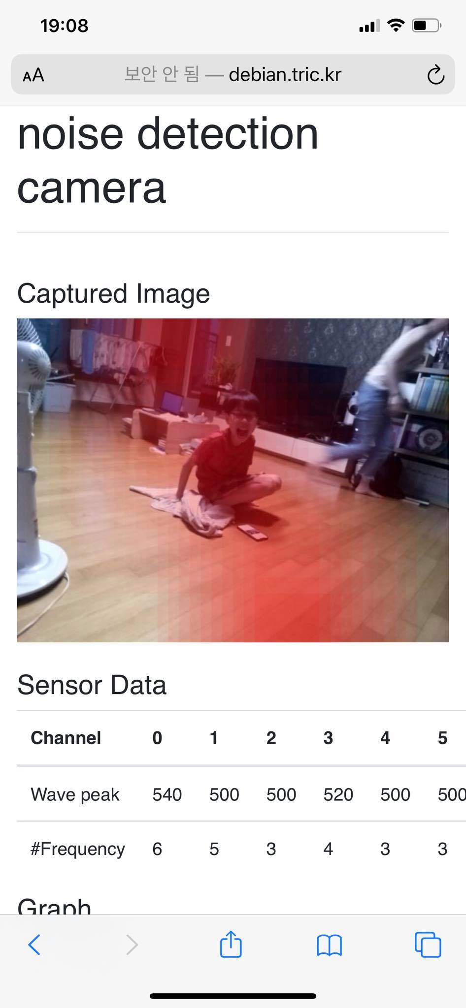
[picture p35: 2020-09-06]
images/b1.jpg

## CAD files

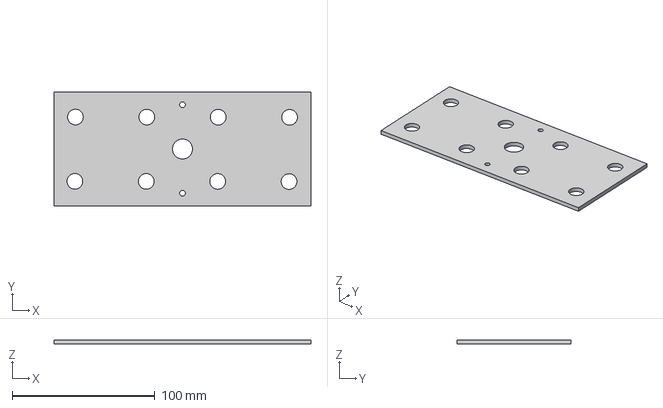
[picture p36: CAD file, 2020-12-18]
model/camera/step/sound-camera.step
180.0 x 80.0 x 3.00 mm

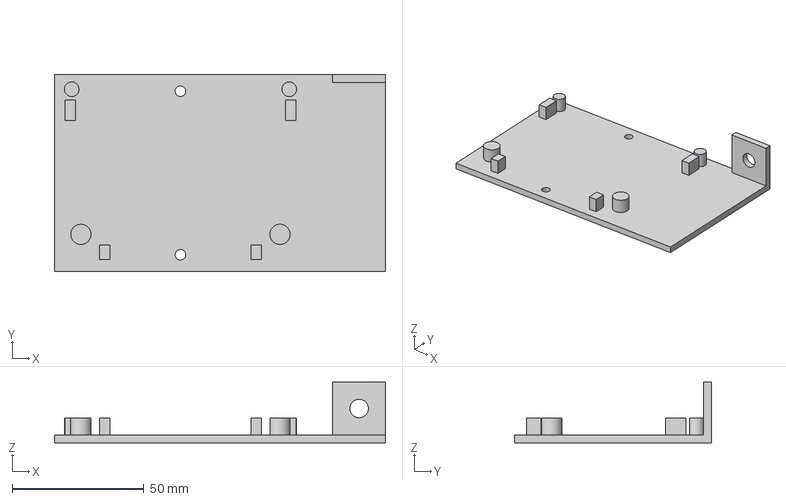
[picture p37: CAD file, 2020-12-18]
model/camera/step/rasp.step
125.5 x 74.5 x 23.0 mm

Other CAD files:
model/camera/f3d/rasp.f3d
model/camera/f3d/sound-camera.f3d
model/camera/stl/rasp.stl
model/camera/stl/sound-camera.stl

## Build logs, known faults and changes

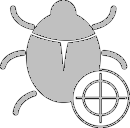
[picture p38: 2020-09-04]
camera/shared/res/debug2.png

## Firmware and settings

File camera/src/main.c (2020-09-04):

/*********************************************************************************************

Special purpose Sound/Noise Detection Camera

Description:
	A SOURCE package to detect a noise around me and capture picture with camera.
	we will find out which places and points make a noise.
	because camera give a picture mapping noise heat map.

Files:
	adc-mcp3008.c	- mcp3008(ADC) control
	fft.c			- fast fourier(cosine/sine) transform
	soundcamera.c	- main module (base UI, logic)

References:
	* Tizen school (https://tizenschool.org/)

Copyright:
	Copyright(C) 2020 WB9LAB (wannabe 9, lab)
	email: haeyun@gmail.com
	download: https://github.com/pushdown99/sound-camera
	You may use, copy, modify this code for any purpose and without fee.

History:
	...
	Aug, 2020 : Edit the Sound/Noise Camera
	Sep, 2020 : Using FFT(Fast Fourier Transform)

 *******************************************************************************************/


#include <mcp3008.h>
#include "soundcam.h"

////////////////////////////////////////////////////////////////////////////////////////////////////////

Eina_Bool doIdler(void *data) {
	appdata_t *ad = (appdata_t*)data;

	/* draw mini map */
	for (int i = 0; i < R_SENSOR; i++) {
		for (int j = 0; j < C_SENSOR; j++) {
			int k = (i * R_SENSOR) + j;
			if (ad->max4466[k].o) evas_object_color_set(ad->minimap[i][j], 255, 0, 0, ad->max4466[k].o);
			else                  evas_object_color_set(ad->minimap[i][j], 255, 0, 0, 5);
		}
	}

	/* draw heat map */
	for (int i = 0; i < R_HEATMAP; i++) {
		for (int j = 0; j < C_HEATMAP; j++) {
			evas_object_color_set(ad->heatmap[i][j], 255, 0, 0, ad->h[i][j]);
		}
	}
	if (ad->snapshot == true) {
		capCAM(data);
		ad->snapshot = false;
	}

	/* check ad->nfail */
	if(ad->nfail > THRESHOLD) {
		evas_object_hide (ad->conn);
		evas_object_show (ad->disc);
		ad->nfail   = 0;
		ad->network = 0;
	}
	if(ad->snap) {
		ad->snap = 0;
		capCAM(data);
	}

	return ECORE_CALLBACK_RENEW;
}

/*
 * Application event handler
 * =========================
 *
 * - create (initialize resource)
 * - control (call ecore_idler, not thread. because we need a exchanging appdata_t pointer)
 * - terminate (resource free)
 *
 */
bool initAPP (void *data)
{
	appdata_t *ad = (appdata_t*)data;
	ad->verbose = 0;
	ad->nfail 	= 0;
	ad->network = 1;
	ad->peak 	= 500;
	ad->freq 	= 1;
	ad->snap	= 0;

	initCURL   (data);
	initGUI    (data);
	initCAM    (data);
	initThread (data);

	return true;
}

void ctrlAPP(app_control_h app_control, void *data)
{
	appdata_t *ad = (appdata_t*)data;

	if (ad->idler) {
		ecore_idler_del(ad->idler);
		ad->idler = NULL;
	}
	ad->idler = ecore_idler_add(doIdler, data);
	if (!ad->idler) _E("Failed to add idler");
}

void termAPP (void *data)
{
	//ecore_evas_shutdown();
}


int main(int argc, char *argv[])
{
	_E("\n\n\n\n");
	_E("==============================================");
	_E("SOUNDCAMERA, WNB-TEAM                         ");
	_E("- started : %s", getTime ()                    );
	_E("- timstamp: %d", getUnixtime ()                );
	_E("==============================================");

	appdata_t ad;
	ui_app_lifecycle_callback_s event_callback = {0,};

	ad.idler = NULL;

	event_callback.create      = initAPP;
	event_callback.terminate   = termAPP;
	event_callback.app_control = ctrlAPP;
	return ui_app_main(argc, argv, &event_callback, &ad);
}

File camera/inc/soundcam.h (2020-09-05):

#ifndef __soundcamera_H__
#define __soundcamera_H__

#ifdef __cplusplus
extern "C" {
#endif

#include <camera.h>
#include <Elementary.h>
#include <system_settings.h>
#include <efl_extension.h>
#include <dlog.h>
#include <app.h>
#include <app_common.h>
#include <stdio.h>
#include <time.h>
#include <stdint.h>
#include <tizen.h>
#include <Ecore.h>
#include <curl/curl.h>
#include <peripheral_io.h>

#include "cam.h"
#include "misc.h"
#include "post.h"
#include "piezoe.h"
#include "fourier.h"
#include "baseUI.h"
#include "thread.h"
#include "debug.h"
#include "max4466.h"
#include "mcp3008.h"

#ifdef  LOG_TAG
#undef  LOG_TAG
#endif
#define LOG_TAG "soundcamera"

#if !defined(PACKAGE)
#define PACKAGE "org.example.soundcamera"
#endif

#define _E(fmt, args...) dlog_print(DLOG_ERROR, LOG_TAG, "%s : %s(%d) > "fmt"\n", rindex(__FILE__, '/') + 1, __func__, __LINE__, ##args)
#define _D(fmt, args...) dlog_print(DLOG_DEBUG, LOG_TAG, "%s : %s(%d) > "fmt"\n", rindex(__FILE__, '/') + 1, __func__, __LINE__, ##args)
#define retv_if(expr, val) do { if (expr) { _E("(%s) -> %s() return", #expr, __FUNCTION__); return (val); } } while (0)

#define FAILURE  		0
#define SUCCESS  		1

#define FOREVER			1

#define NSAMPLE			128 				// SOUND SIGNAL SAMPLING RATE, 2^m
#define NSENSOR			8					// NSENSOR = C_SENSOR (COL) x R_SENSOR (ROW)
#define C_SENSOR		4
#define R_SENSOR		2
#define WIDTH			640					// PREVIEW IMAGE WIDTH
#define HEIGHT          480					// PREVIEW IMAGE HEIGHT
#define QUALITY 		100
#define S_WIDTH         (WIDTH/C_SENSOR)  	// SENSOR WIDTH  (SENSOR MAPPED), 160
#define S_HEIGHT        (HEIGHT/R_SENSOR)   // SENSOR HEIGHT (SENSOR MAPPED), 240
#define HEATMAP         10                  // MATRIX (10 x 10)
#define H_WIDTH         (S_WIDTH/HEATMAP)   // HEATMAP CELL WIDTH, 16
#define H_HEIGHT        (S_HEIGHT/HEATMAP)  // HEATMAP CELL HEIGHT, 24
#define C_HEATMAP		(C_SENSOR*HEATMAP)
#define R_HEATMAP		(R_SENSOR*HEATMAP)
#define M_WIDTH			140
#define M_HEIGHT        105

#define B_WIDTH			140 	// shutter button
#define B_HEIGHT        140
#define BORDER          5
#define I_WIDTH			40 		// icon button
#define I_HEIGHT        40
#define I_GAP			10
#define KERNEL          HEATMAP 		// needed odd value (like 1,3,5,...) 5 <- normal

#define SHOT_PNG		"shot.png"
#define SHOT2_PNG		"shot2.png"
#define EXIT_PNG		"exit.png"
#define CAPTURE_JPG		"capture.jpg"
#define WINDOW_JPG		"window.jpg"
#define PREVIEW_JPG		"preview.jpg"
#define DEBUG_PNG		"debug.png"
#define DEBUG2_PNG		"debug2.png"
#define CONN_PNG		"connect.png"
#define DISC_PNG		"disconnect.png"

/*
 *  DISPLAY SCREEN LAYOUT
 *  =====================
 *
 *  - Raspberry Pi 7" Touch Screen Display (800 x 600)
 *
 *   <------------ 640 --------------> <----- 160 ----->
 * 	+---------------------------------+-----------------+
 * 	|(0,0)                            | +-------------+ |    noise map
 * 	|                                 | |  NOISE MAP  | |    (120 x 90; 4:3)
 * 	|         CAMERA PREVIEW          | |             | |
 * 	|          (640 x 480)            | +-------------+ |
 * 	|                                 | +-------------+ |
 * 	|                                 | |  SHUTTER    | |
 * 	|                                 | +-------------+ |
 * 	|                                 | +-------------+ |
 * 	|                                 | |  EXIT       | |
 * 	|                        (640,480)| +-------------+ |
 * 	+---------------------------------+-----------------+
 * 	                                   <>              <> 20 (BORDER)
 *                                       <----120----->
 *
 *  SENSOR LAYOUT @CAMERA PREVIEW
 *  =============================
 *
 *  - SCREEN: width x height  = 640 x 380 (4:3)
 *  - SENSOR: width x height  = 160 x 240
 *
 *  <--------------------------640-------------------------->
 *  <----160------> width
 * 	+-------------+-------------+-------------+-------------+
 * 	|             |             |             |             |
 * 	|             |             |             |             |
 * 	|             |             |             |             |
 * 	|  SENSOR#0   |  SENSOR#1   |  SENSOR#2   |  SENSOR#3   |
 * 	|             |             |             |             |
 * 	|             |             |             |             |
 * 	|             |             |             |             |
 * 	|             |             |             |             |
 * 	+-------------+-------------+-------------+-------------+
 * 	|             |             |             |             |
 * 	|             |             |             |             |
 * 	|             |             |             |             |
 * 	|  SENSOR#4   |  SENSOR#5   |  SENSOR#6   |  SENSOR#7   |
 * 	|             |             |             |             |
 * 	|             |             |             |             |
 * 	|             |             |             |             |
 * 	|             |             |             |             |
 * 	+-------------+-------------+-------------+-------------+
 *
 *  HEATMAP CELL LAYOUT @SENSOR
 *  ===========================
 *
 *	- SENSOR: width x height = 160 x 240
 *	- CELL: width x height = 16 x 24 (10 x 10 matrix)
 *  <-16->
 *  +----+----+----+----+----+----+----+----+----+----+
 *  | 00 | 01 | 02 | 03 | 04 | 05 | 06 | 07 | 08 | 08 |
 *  +----+----+----+----+----+----+----+----+----+----+
 *  | 01 |    |    |    |    |    |    |    |    |    |
 *  +----+----+----+----+----+----+----+----+----+----+
 *  | 02 |    |    |    |    |    |    |    |    |    |
 *  +----+----+----+----+----+----+----+----+----+----+
 *  | 03 |    |    |    |    |    |    |    |    |    |
 *  +----+----+----+----+----+----+----+----+----+----+
 *  | 04 |    |    |    |    |    |    |    |    |    |
 *  +----+----+----+----+----+----+----+----+----+----+
 *  | 05 |    |    |    |    |    |    |    |    |    |
 *  +----+----+----+----+----+----+----+----+----+----+
 *  | 06 |    |    |    |    |    |    |    |    |    |
 *  +----+----+----+----+----+----+----+----+----+----+
 *  | 07 |    |    |    |    |    |    |    |    |    |
 *  +----+----+----+----+----+----+----+----+----+----+
 *  | 08 |    |    |    |    |    |    |    |    |    |
 *  +----+----+----+----+----+----+----+----+----+----+
 *  | 09 |    |    |    |    |    |    |    |    |    |
 *  +----+----+----+----+----+----+----+----+----+----+
 *
 */

#define	HIGH			1
#define LOW				0
#define GPIO_PIEZOE		20
#define GPIO_BUTTON		21
#define PUSH            1
#define TIMEOUT			1
#define THRESHOLD       50

typedef struct {
	int			id;								// sensor #id
	int     	p;								// peak value
	int     	n;                  			// frequency count
	int			o;								// opaque (0..255)
	int			v[NSAMPLE];						// sensor read value
	int 		f[NSAMPLE];						// fast fourier transform matrix mapping value
	double 		a[NSAMPLE];						// fast fourier transform matrix
	void* 		data;
} max4466_t;
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
